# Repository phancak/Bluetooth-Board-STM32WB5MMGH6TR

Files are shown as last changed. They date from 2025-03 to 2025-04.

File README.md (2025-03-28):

# STM32WB5MMGH6TR Bluetooth Expansion Board  

## Overview  
This project features a **Bluetooth expansion board** based on the **STM32WB5MMGH6TR module**, designed for seamless integration with various embedded systems. The board provides flexible connectivity through **I2C, USART, and SPI**, making it an ideal solution for rapid prototyping and system expansion.  

Engineered for **low-power applications** and **high-performance wireless communication**, this board serves as a versatile platform for **IoT, industrial automation, and smart embedded devices**.  

## Features  
✅ **STM32WB5MMGH6TR Module** – Dual-core Cortex-M4/M0+ with BLE 5.2 support  
✅ **Multiple Communication Interfaces** – I2C, USART, and SPI for seamless integration  
✅ **Compact and Modular Design** – Easily integrates with other MCU-based projects  
✅ **Low-Power Optimization** – Suitable for battery-powered applications  
✅ **Expandable & Customizable** – Compatible with additional peripherals  

## Applications  
- **IoT Devices** – Wireless sensors, smart home automation  
- **Industrial Monitoring** – Data acquisition, remote control systems  
- **Embedded Systems Development** – Ideal for prototyping and experimentation  

## Getting Started  
### Hardware Requirements  
- STM32WB5MMGH6TR Bluetooth Expansion Board  
- Host MCU (STM32, ESP32, etc.)  
- Power Supply (3.3V)  
- Serial Debugging Tools (USB-to-Serial Adapter)  

### Software Requirements  
- **STM32CubeIDE** – For firmware development  
- **STM32CubeWB** – Bluetooth stack and middleware  
- **Segger J-Link or ST-Link** – For debugging and flashing  

## Setup & Usage  
1. **Power the Board** – Provide 3.3V via USB or external power source.  
2. **Connect to Host MCU** – Use I2C, USART, or SPI for communication.  
3. **Flash Firmware** – Use STM32CubeIDE or STM32CubeProgrammer.  
4. **Test Bluetooth Functionality** – Verify BLE communication using a mobile app or a central device.  

## Repository Structure  
/Hardware        - PCB schematics and design files  
  /Schematic      - Circuit diagrams (PDF, KiCad, Altium, etc.)  
  /PCB            - Board layout files (Gerber, BOM, assembly files)  

## Future Enhancements  
- 🔹 **Additional Protocol Support** – Expanding compatibility with more peripherals  
- 🔹 **Power Optimization** – Fine-tuning sleep modes for ultra-low power consumption  
- 🔹 **Custom BLE Services** – Implementing advanced communication features  

## License  
This project is open-source under the **MIT License**.  

---

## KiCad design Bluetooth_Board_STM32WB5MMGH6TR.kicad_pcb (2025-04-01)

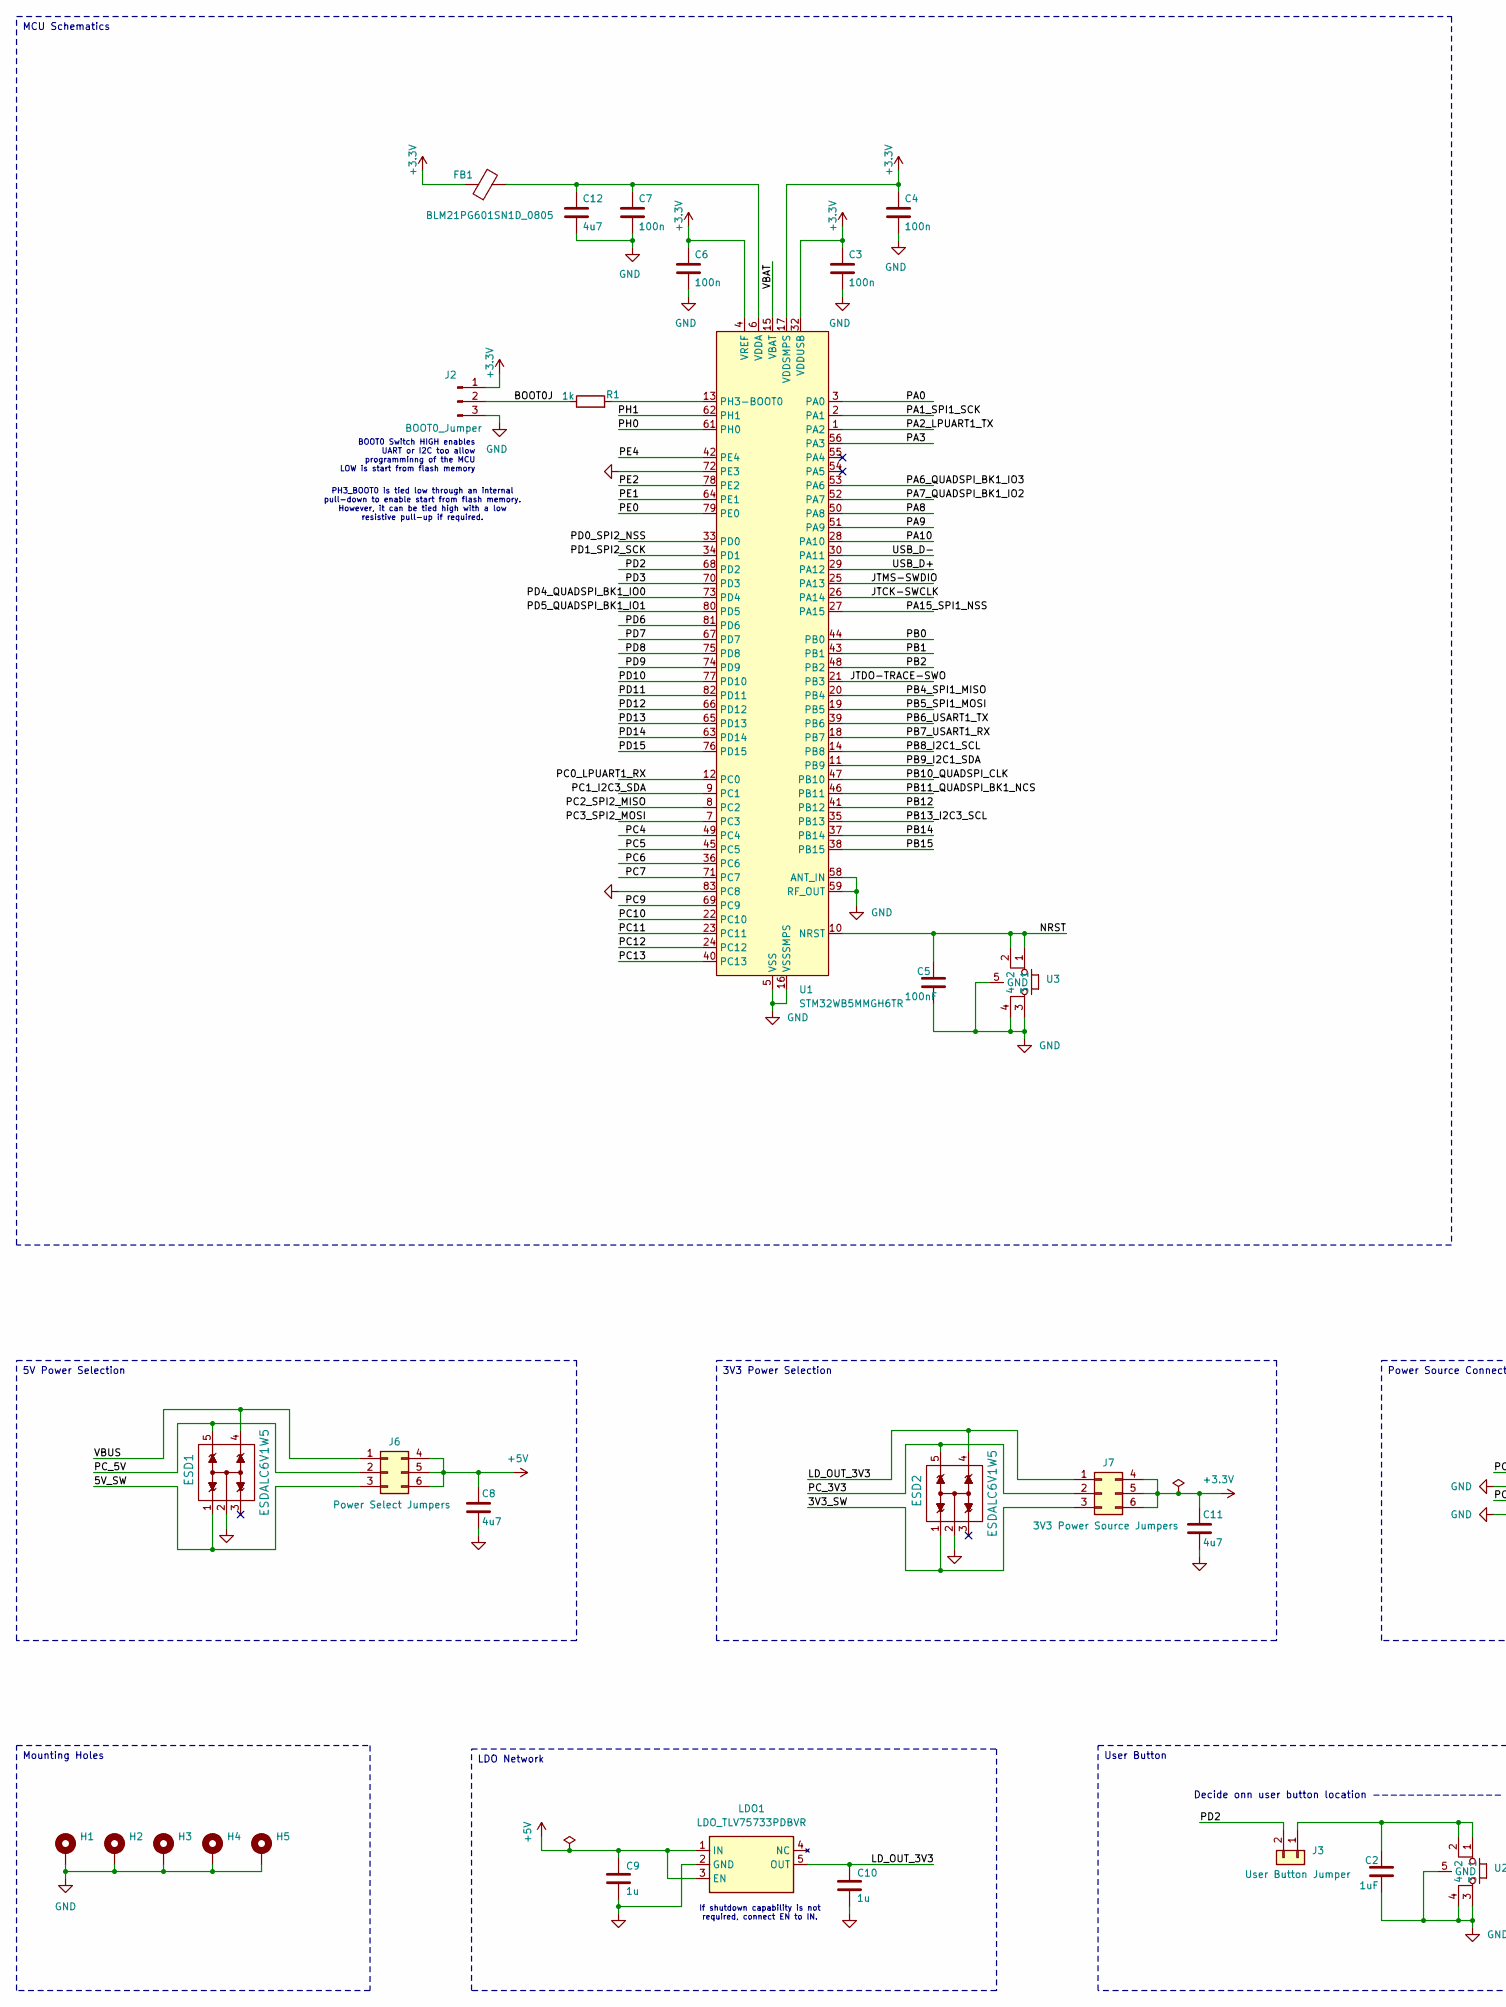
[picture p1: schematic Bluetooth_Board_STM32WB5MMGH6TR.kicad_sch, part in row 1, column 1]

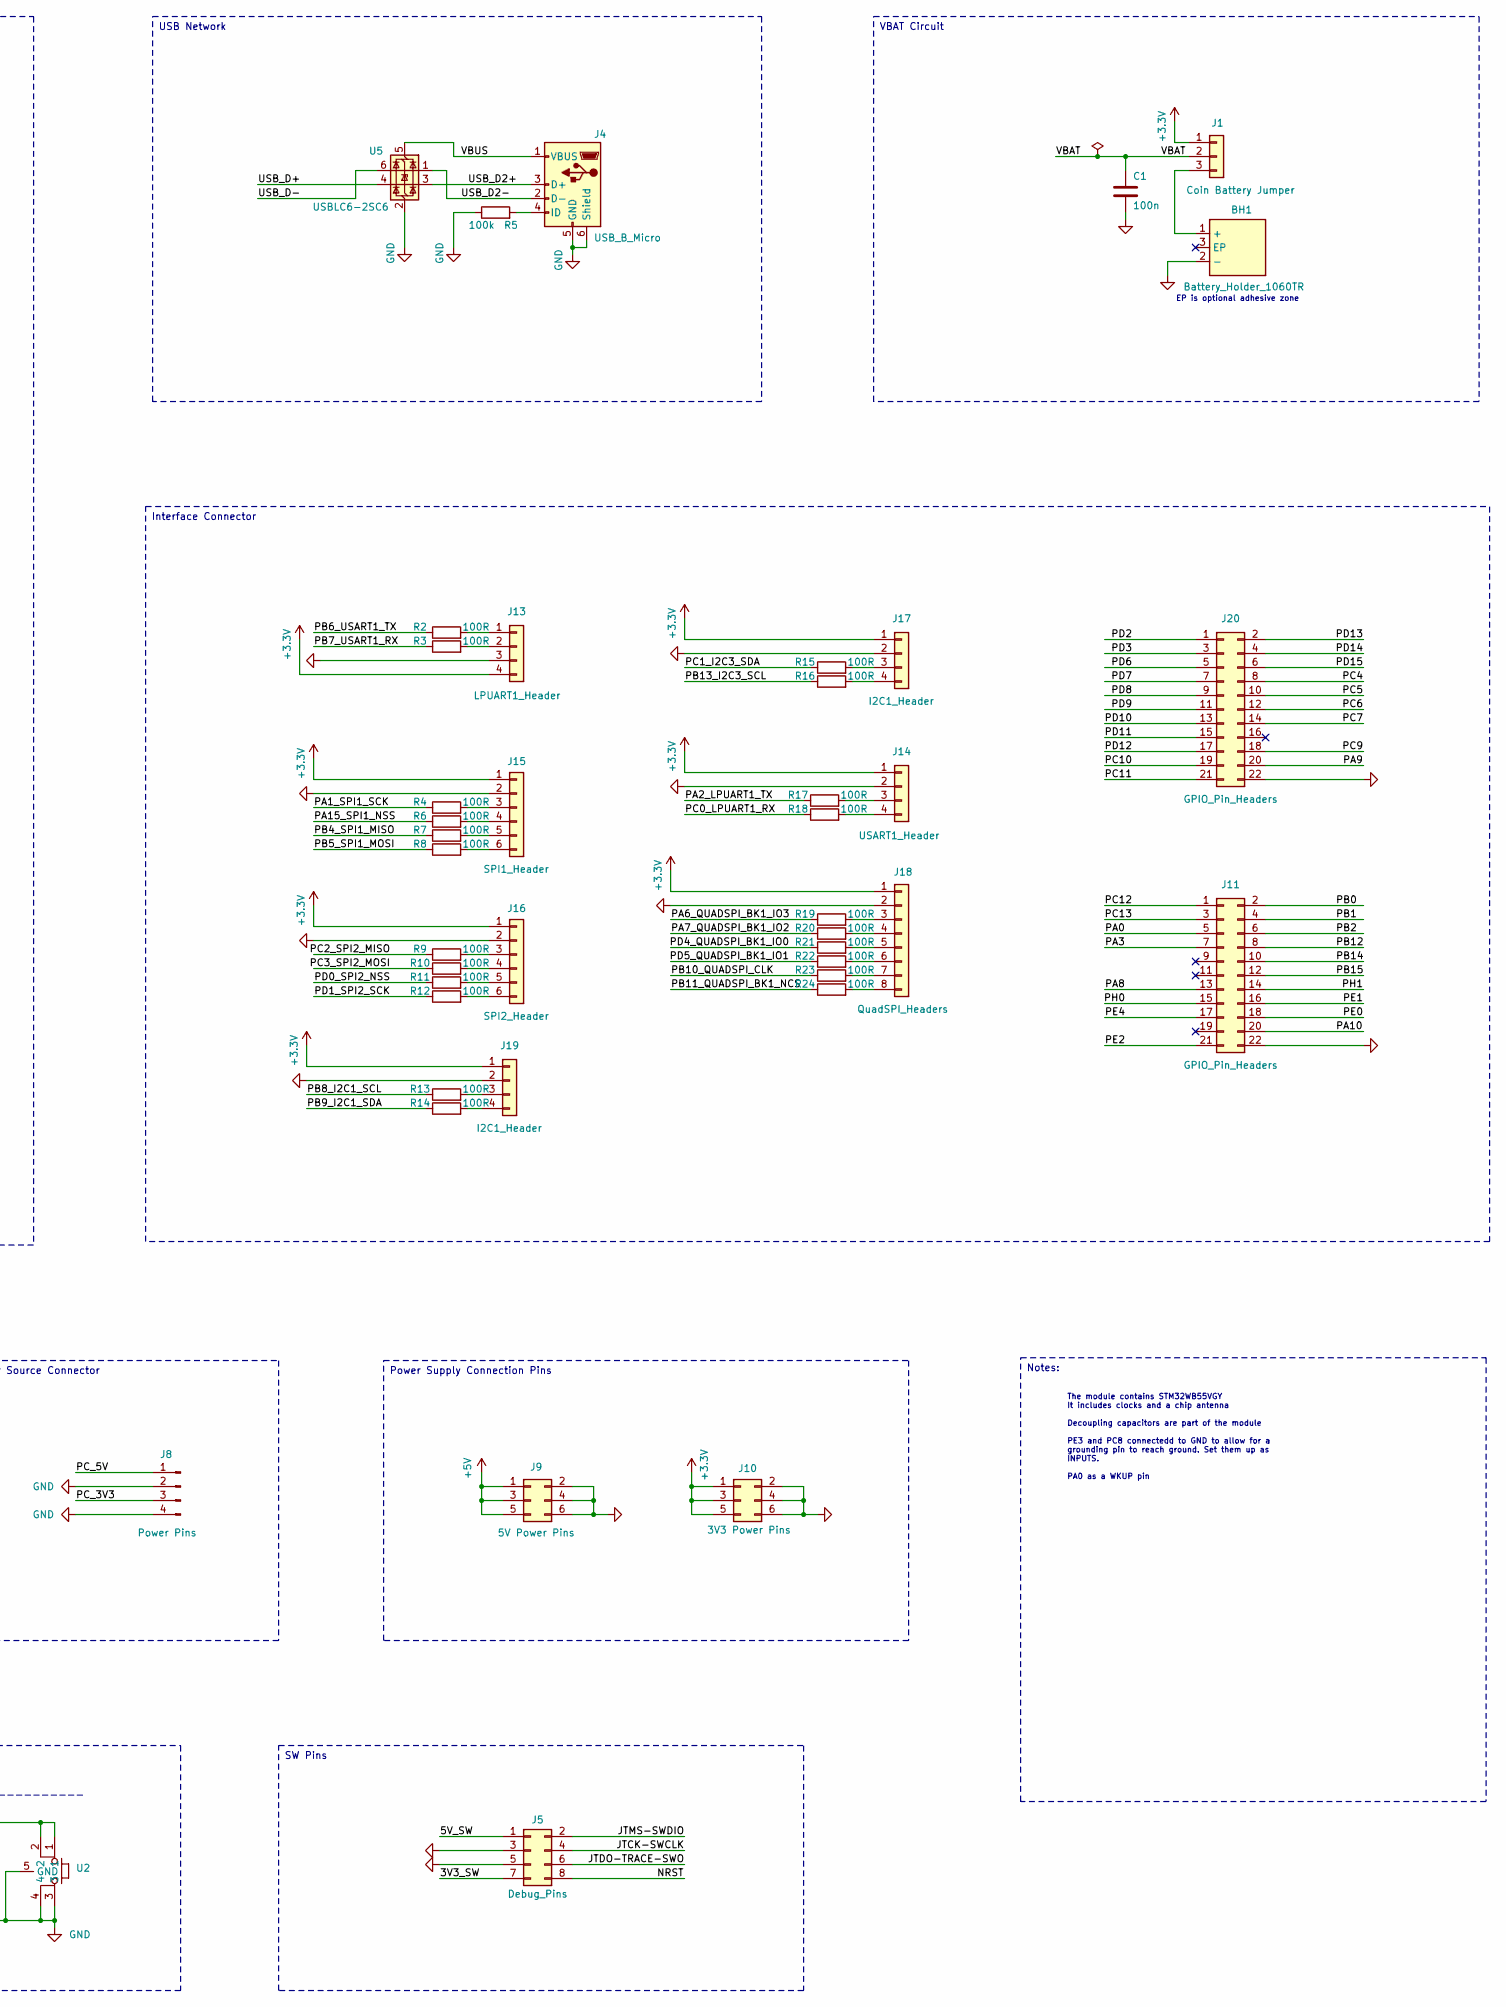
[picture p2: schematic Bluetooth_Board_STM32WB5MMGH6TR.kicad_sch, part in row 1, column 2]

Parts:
BH1: Battery_Holder_1060TR; Mouser Part Number 534-1060TR
C1, C3, C4, C6, C7: 100n; C_0805_2012Metric_Pad1.18x1.45mm_HandSolder
C2: 1uF; C_0603_1608Metric_Pad1.08x0.95mm_HandSolder
C5: 100nF; C_0805_2012Metric_Pad1.18x1.45mm_HandSolder
C8, C11: 4u7; C_0603_1608Metric_Pad1.08x0.95mm_HandSolder
C9, C10: 1u; C_0603_1608Metric_Pad1.08x0.95mm_HandSolder
C12: 4u7; C_0805_2012Metric_Pad1.18x1.45mm_HandSolder
ESD1, ESD2: ESDALC6V1W5; SOT323-5L_STM-L
FB1: BLM21PG601SN1D_0805; C_0805_2012Metric_Pad1.18x1.45mm_HandSolder
H1, H2, H3, H4, H5: MountingHole_Pad; MountingHole_3.2mm_M3_Pad
J1: Coin Battery Jumper; PinHeader_1x03_P2.54mm_Vertical
J2: BOOT0_Jumper; PinHeader_1x03_P2.54mm_Vertical
J3: User Button Jumper; PinHeader_1x02_P2.54mm_Vertical
J4: USB_B_Micro; USB_Micro-B_Molex-105017-0001
J5: Debug_Pins; PinHeader_2x04_P2.54mm_Vertical
J6: Power Select Jumpers; PinHeader_2x03_P2.54mm_Vertical_PINS
J7: 3V3 Power Source Jumpers; PinHeader_2x03_P2.54mm_Vertical_PINS
J8: Power Pins; PinHeader_1x04_P2.54mm_Vertical
J9: 5V Power Pins; PinHeader_2x03_P2.54mm_Vertical
J10: 3V3 Power Pins; PinHeader_2x03_P2.54mm_Vertical
J11, J20: GPIO_Pin_Headers; PinHeader_2x11_P2.54mm_Vertical
J13: LPUART1_Header; PinHeader_1x04_P2.54mm_Vertical
J14: USART1_Header; PinHeader_1x04_P2.54mm_Vertical
J15: SPI1_Header; PinHeader_1x06_P2.54mm_Vertical
J16: SPI2_Header; PinHeader_1x06_P2.54mm_Vertical
J17, J19: I2C1_Header; PinHeader_1x04_P2.54mm_Vertical
J18: QuadSPI_Headers; PinHeader_1x08_P2.54mm_Vertical
LDO1: LDO_TLV75733PDBVR; LDO_SOT95P280X145-5N; Mouser Part Number 595-TLV75733PDBVR
R1: 1k; R_0805_2012Metric_Pad1.20x1.40mm_HandSolder
R2, R3, R4, R6, R7, R8, R9, R10, R11, R12, R13, R14, R15, R16, R17, R18, R19, R20, R21, R22, R23, R24: 100R; R_0805_2012Metric_Pad1.20x1.40mm_HandSolder
R5: 100k; R_0603_1608Metric_Pad0.98x0.95mm_HandSolder
U1: STM32WB5MMGH6TR; ST-SiP-LGA-86-11x7.3mm
U2, U3: Button_KMR231GLFS
U5: USBLC6-2SC6; SOT-23-6

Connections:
+3.3V: C3.1, C4.1, C6.1, C11.1, FB1.1, J1.1, J2.1, J7.4, J7.5, J7.6, J10.1, J10.3, J10.5, J13.4, J14.1, J15.1, J16.1, J17.1, J18.1, J19.1, U1.4 (VREF), U1.17 (VDDSMPS), U1.32 (VDDUSB)
+5V: C8.1, C9.1, J6.4, J6.5, J6.6, J9.1, J9.3, J9.5, LDO1.1 (IN), LDO1.3 (EN)
/3V3_SW: ESD2.1 (I/O1), J5.7, J7.3
/5V_SW: ESD1.1 (I/O1), J5.1, J6.3
/BOOT0J: J2.2, R1.1
/JTCK-SWCLK: J5.4, U1.26 (PA14)
/JTDO-TRACE-SWO: J5.6, U1.21 (PB3)
/JTMS-SWDIO: J5.2, U1.25 (PA13)
/LD_OUT_3V3: C10.1, ESD2.4 (I/O3), J7.1, LDO1.5 (OUT)
/NRST: C5.2, J5.8, U1.10 (NRST), U3.1, U3.2
/PA0: J11.5, U1.3 (PA0)
/PA1_SPI1_SCK: R4.1, U1.2 (PA1)
/PA2_LPUART1_TX: R17.1, U1.1 (PA2)
/PA3: J11.7, U1.56 (PA3)
/PA6_QUADSPI_BK1_IO3: R19.1, U1.53 (PA6)
/PA7_QUADSPI_BK1_IO2: R20.1, U1.52 (PA7)
/PA8: J11.13, U1.50 (PA8)
/PA9: J20.20, U1.51 (PA9)
/PA10: J11.20, U1.28 (PA10)
/PA15_SPI1_NSS: R6.1, U1.27 (PA15)
/PB0: J11.2, U1.44 (PB0)
/PB1: J11.4, U1.43 (PB1)
/PB2: J11.6, U1.48 (PB2)
/PB4_SPI1_MISO: R7.1, U1.20 (PB4)
/PB5_SPI1_MOSI: R8.1, U1.19 (PB5)
/PB6_USART1_TX: R2.1, U1.39 (PB6)
/PB7_USART1_RX: R3.1, U1.18 (PB7)
/PB8_I2C1_SCL: R13.1, U1.14 (PB8)
/PB9_I2C1_SDA: R14.1, U1.11 (PB9)
/PB10_QUADSPI_CLK: R23.1, U1.47 (PB10)
/PB11_QUADSPI_BK1_NCS: R24.1, U1.46 (PB11)
/PB12: J11.8, U1.41 (PB12)
/PB13_I2C3_SCL: R16.1, U1.35 (PB13)
/PB14: J11.10, U1.37 (PB14)
/PB15: J11.12, U1.38 (PB15)
/PC0_LPUART1_RX: R18.1, U1.12 (PC0)
/PC1_I2C3_SDA: R15.1, U1.9 (PC1)
/PC2_SPI2_MISO: R9.1, U1.8 (PC2)
/PC3_SPI2_MOSI: R10.1, U1.7 (PC3)
/PC4: J20.8, U1.49 (PC4)
/PC5: J20.10, U1.45 (PC5)
/PC6: J20.12, U1.36 (PC6)
/PC7: J20.14, U1.71 (PC7)
/PC9: J20.18, U1.69 (PC9)
/PC10: J20.19, U1.22 (PC10)
/PC11: J20.21, U1.23 (PC11)
/PC12: J11.1, U1.24 (PC12)
/PC13: J11.3, U1.40 (PC13)
/PC_3V3: ESD2.5 (I/O4), J7.2, J8.3
/PC_5V: ESD1.5 (I/O4), J6.2, J8.1
/PD0_SPI2_NSS: R11.1, U1.33 (PD0)
/PD1_SPI2_SCK: R12.1, U1.34 (PD1)
/PD2: J3.2, J20.1, U1.68 (PD2)
/PD3: J20.3, U1.70 (PD3)
/PD4_QUADSPI_BK1_IO0: R21.1, U1.73 (PD4)
/PD5_QUADSPI_BK1_IO1: R22.1, U1.80 (PD5)
/PD6: J20.5, U1.81 (PD6)
/PD7: J20.7, U1.67 (PD7)
/PD8: J20.9, U1.75 (PD8)
/PD9: J20.11, U1.74 (PD9)
/PD10: J20.13, U1.77 (PD10)
/PD11: J20.15, U1.82 (PD11)
/PD12: J20.17, U1.66 (PD12)
/PD13: J20.2, U1.65 (PD13)
/PD14: J20.4, U1.63 (PD14)
/PD15: J20.6, U1.76 (PD15)
/PE0: J11.18, U1.79 (PE0)
/PE1: J11.16, U1.64 (PE1)
/PE2: J11.21, U1.78 (PE2)
/PE4: J11.17, U1.42 (PE4)
/PH0: J11.15, U1.61 (PH0)
/PH1: J11.14, U1.62 (PH1)
/USB_D2+: J4.3 (D+), U5.3 (I/O2)
/USB_D2-: J4.2 (D-), U5.1 (I/O1)
/USB_D+: U1.29 (PA12), U5.4 (I/O2)
/USB_D-: U1.30 (PA11), U5.6 (I/O1)
/VBAT: C1.1, J1.2, U1.15 (VBAT)
/VBUS: ESD1.4 (I/O3), J4.1 (VBUS), J6.1, U5.5 (VBUS)
GND: BH1.2 (-), C1.2, C2.1, C3.2, C4.2, C5.1, C6.2, C7.2, C8.2, C9.2, C10.2, C11.2, C12.2, ESD1.2 (GND), ESD2.2 (GND), H1.1, H2.1, H3.1, H4.1, H5.1, J2.3, J4.5 (GND), J4.6 (Shield), J5.3, J5.5, J8.2, J8.4, J9.2, J9.4, J9.6, J10.2, J10.4, J10.6, J11.22, J13.3, J14.2, J15.2, J16.2, J17.2, J18.2, J19.2, J20.22, LDO1.2 (GND), R5.1, U1.5 (VSS), U1.16 (VSSSMPS), U1.31 (VSS), U1.57 (VSS), U1.58 (ANT_IN), U1.59 (RF_OUT), U1.60 (VSS), U1.72 (PE3), U1.83 (PC8), U1.84 (VSS), U1.86 (VSS), U2.3, U2.4, U2.5 (GND), U3.3, U3.4, U3.5 (GND), U5.2 (GND)
unnamed: BH1.1 (+), J1.3
unnamed: C2.2, J3.1, U2.1, U2.2
unnamed: J4.4 (ID), R5.2
unnamed: J13.1, R2.2
unnamed: J13.2, R3.2
unnamed: J14.3, R17.2
unnamed: J14.4, R18.2
unnamed: J15.3, R4.2
unnamed: J15.4, R6.2
unnamed: J15.5, R7.2
unnamed: J15.6, R8.2
unnamed: J16.3, R9.2
unnamed: J16.4, R10.2
unnamed: J16.5, R11.2
unnamed: J16.6, R12.2
unnamed: J17.3, R15.2
unnamed: J17.4, R16.2
unnamed: J18.3, R19.2
unnamed: J18.4, R20.2
unnamed: J18.5, R21.2
unnamed: J18.6, R22.2
unnamed: J18.7, R23.2
unnamed: J18.8, R24.2
unnamed: J19.3, R13.2
unnamed: J19.4, R14.2
unnamed: R1.2, U1.13 (PH3-BOOT0)
unnamed: C7.1, C12.1, FB1.2, U1.6 (VDDA)

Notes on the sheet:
Power Supply Connection Pins
Power Source Connector
3V3 Power Selection
VBAT Circuit
Notes:
Interface Connector
User Button
SW Pins
5V Power Selection
MCU Schematics
Mounting Holes
LDO Network
USB Network
Decide onn user button location ---------------
EP is optional adhesive zone
BOOT0 Switch HIGH enables UART or I2C too allow programminng of the MCU LOW is start from flash memory
If shutdown capability is not required, connect EN to IN.
PH3_BOOT0 is tied low through an internal pull-down to enable start from flash memory. However, it can be tied high with a low resistive pull-up if required.
The module contains STM32WB55VGY It includes clocks and a chip antenna Decoupling capacitors are part of the module PE3 and PC8 connectedd to GND to allow for a grounding pin to reach ground. Set them up as INPUTS. PA0 as a WKUP pin

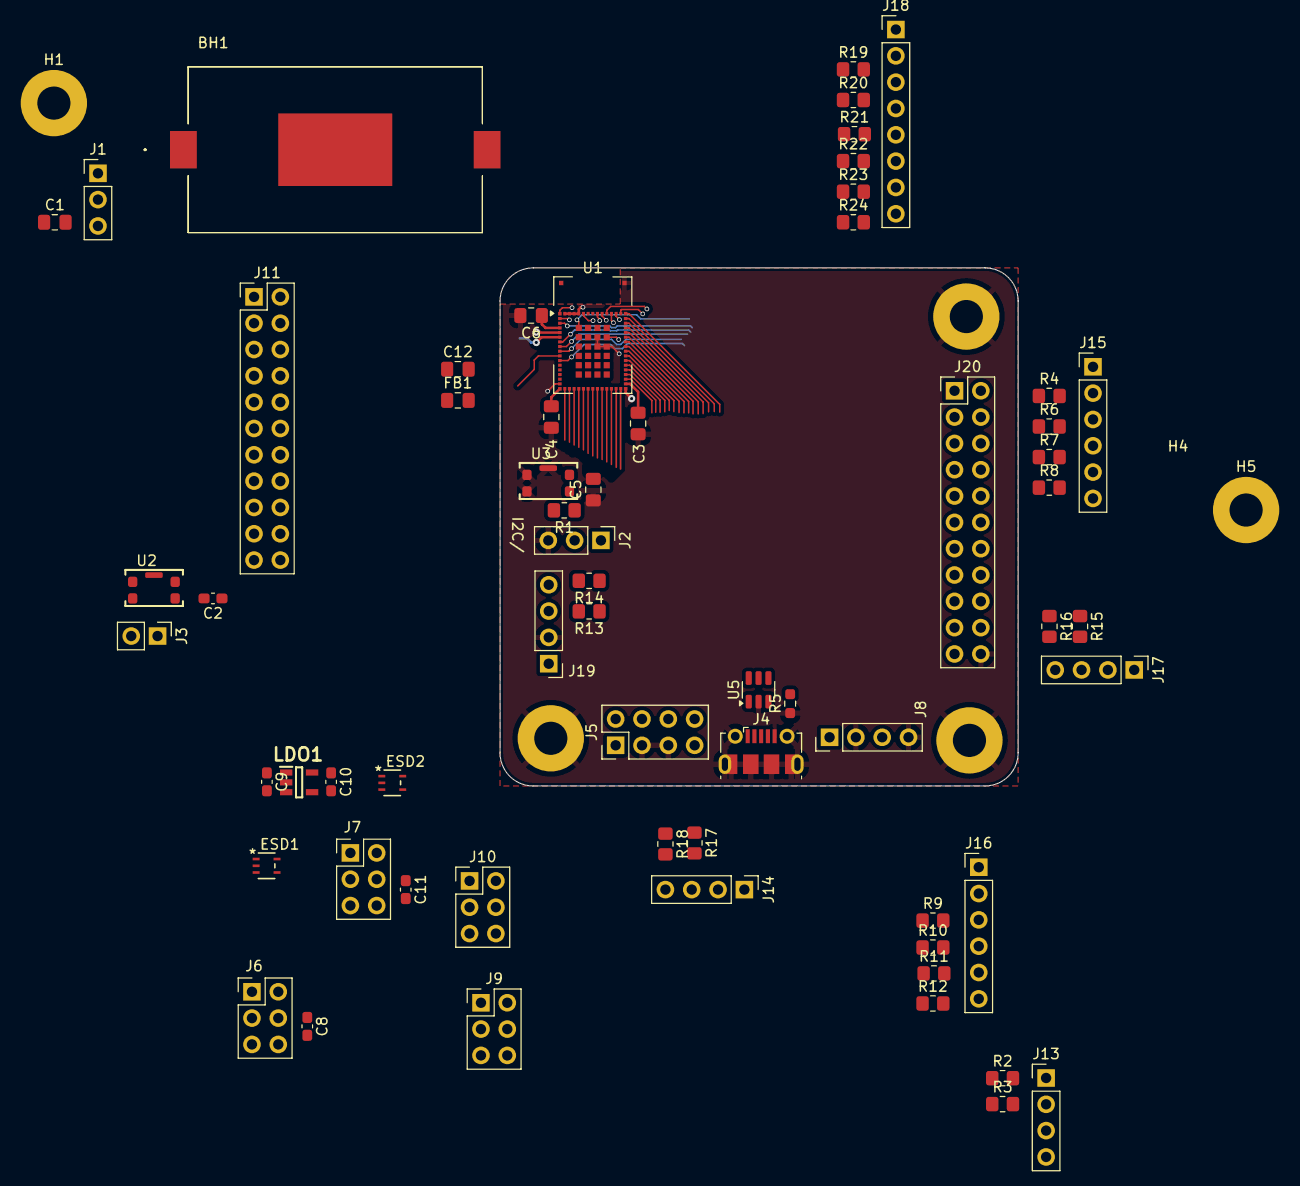
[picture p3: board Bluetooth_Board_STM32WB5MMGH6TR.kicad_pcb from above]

Board: 4 copper layers, 50.0 x 50.0 mm, 69 parts (1 on the bottom side), 106 nets.
